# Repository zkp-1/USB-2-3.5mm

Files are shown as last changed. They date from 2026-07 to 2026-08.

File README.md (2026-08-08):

# USB-2-3.5mm
Personal Project to drive analog speakers from USB Type C.
##
I utilized a Cmedia CM108B audio IC and a MAX97720A Amplifier IC. The USB Type C connector is wired with resistors on CC1 and CC2 to allow power draw from the Host. The Cmedia IC then sends an identifier notifying the Host that the device is an audio device, making it load drivers and prepare for audio playthrough. A 90Ω impedance was aimed for in the design, to allow optimal operation on the differential USB data rails. At last, the IC sends the Audio data through its own DACs and internal amplifiers, converting it to analog and being able to be used at the intended 3.5mm output. 

The MAX97220A is set with a gain of 3.52dB and an input impedance of 10k. The output of the MAX IC is wired directly onto the 3.5mm and has an integrated anti-crackle and pop solution inside the IC, which was my main drive to using this IC for amplification.
# PCB 3D KiCAD Renders
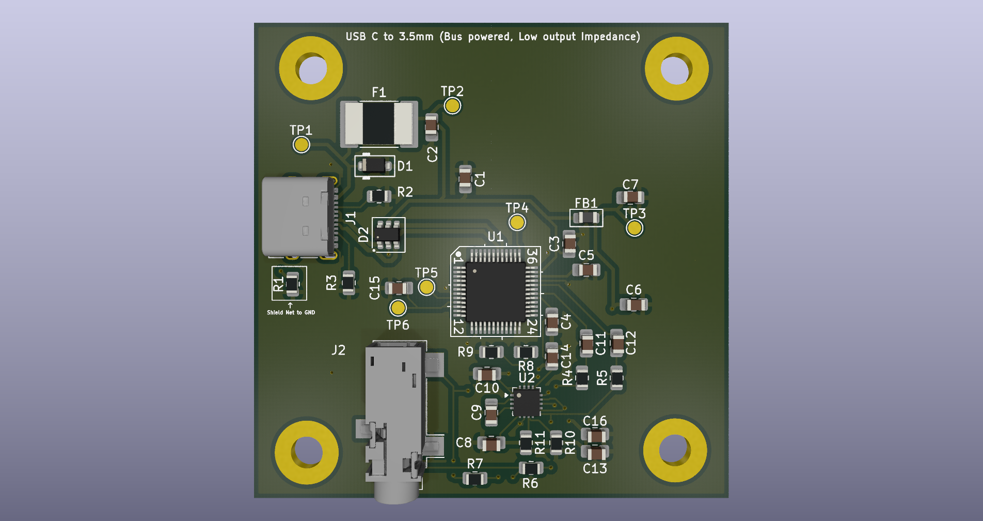
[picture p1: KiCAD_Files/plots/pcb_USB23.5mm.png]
1. 

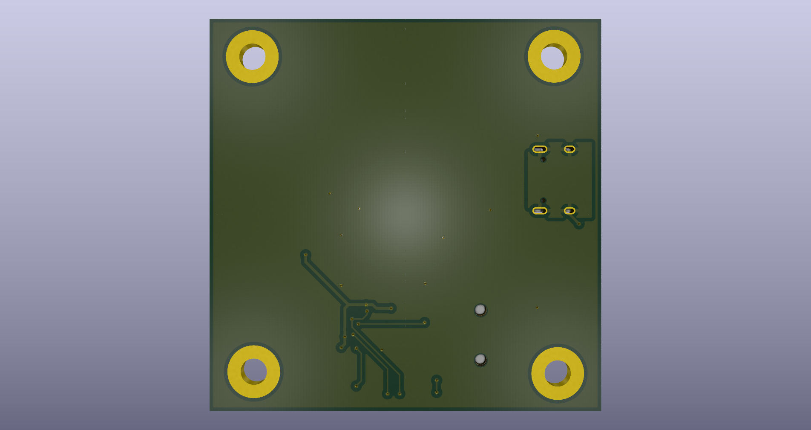
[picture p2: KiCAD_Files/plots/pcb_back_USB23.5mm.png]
2.

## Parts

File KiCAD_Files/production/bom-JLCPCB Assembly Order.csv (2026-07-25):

JLCPCB BOM Tool - BOM Matching
BOM name：bom-JLCPCB Assembly Order.xlsx |  |  | Download Time：2026-07-26 05:52:38 |  |  |  | * Our matching results are updated in real-time, but stock and prices may change. If it's been over 24 hours, please re-match before placing your order.
PCB Assembled Qty：5 |  |  | Est. Total Price：33.1043
Your BOM |  |  |  |  | Matched Parts |  |  |  |  |  |  | Order Information
Top Designator | Bottom Designator | Comment | Footprint | JLCPCB Part # | Matches | Part # | Manufacturer | Footprint | Description | Category | Warning | JLCPCB Part # | Product link | Lib Type | Qty | Source | Total Price ($)
C1,C15,C3,C4,C5,C6 |  | 0.1u | 0805 |  | Unconfirmed | CC0805KRX7R9BB104 | YAGEO | 0805 | 100nF 50V X7R ±10% 0805 Multilayer Ceramic Capacitors MLCC - SMD/SMT ROHS | Multilayer Ceramic Capacitors MLCC - SMD/SMT | 1.The comment (CC0805KRX7R9BB104) of this part does not match the one (0.1u) provided in your BOM. Please confirm; | C49678 | https://jlcpcb.com/partdetail/YAGEO-CC0805KRX7R9BB104/C49678 | Basic | 40 | 40 JLCPCB | 1.284
C10,C13,C14,C16,C8,C9 |  | 1u | 0805 |  | Unconfirmed | CL21B105KBFNNNE | Samsung Electro-Mechanics | 0805 | 1uF 50V X7R ±10% 0805 Multilayer Ceramic Capacitors MLCC - SMD/SMT ROHS | Multilayer Ceramic Capacitors MLCC - SMD/SMT | 1.The comment (CL21B105KBFNNNE) of this part does not match the one (1u) provided in your BOM. Please confirm; | C28323 | https://jlcpcb.com/partdetail/29074-CL21B105KBFNNNE/C28323 | Basic | 40 | 40 JLCPCB | 3.46
C11,C12,C2,C7 |  | 4.7u | 0805 |  | Unconfirmed | CL21A475KAQNNNE | Samsung Electro-Mechanics | 0805 | 25V 4.7uF X5R ±10% 0805 Multilayer Ceramic Capacitors MLCC - SMD/SMT ROHS | Multilayer Ceramic Capacitors MLCC - SMD/SMT | 1.The comment (CL21A475KAQNNNE) of this part does not match the one (4.7u) provided in your BOM. Please confirm; | C1779 | https://jlcpcb.com/partdetail/2131-CL21A475KAQNNNE/C1779 | Basic | 30 | 30 JLCPCB | 1.506
D1 |  | TVS_Uni | D_SOD-123F |  | Select by Customer | M4SMF15CA | Slkor(SLKORMICRO Elec.) | SOD-123FL | 15V 18.5V 180A@8/20us 1uA 26V 500pF Bidirectional TVS SOD-123FL ESD and Surge Protection (TVS/ESD) ROHS |  |  | C46061815 | https://jlcpcb.com/partdetail/Slkor_SLKORMICRO_Elec-M4SMF15CA/C46061815 | Extended | 15 | 15 JLCPCB | 0.624
D2 |  | USBLC6-2SC6 | SOT-23-6 |  | Select by System | USBLC6-2SC6 | TECH PUBLIC | SOT-23-6 | -55℃~+125℃ 0.35pF 12V 150W 2 5V 6A 6V 80nA ESD IEC 61000-4-2、IEC 61000-4-5、IEC 61000-4-4 Unidirectional SOT-23-6 ESD and Surge Protection (TVS/ESD) ROHS | ESD And Surge Protection (TVS/ESD) |  | C2827654 | https://jlcpcb.com/partdetail/TECHPUBLIC-USBLC62SC6/C2827654 | Extended | 9 | 9 JLCPCB | 0.3978
F1 |  | Polyfuse_S | 2920 |  | Select by Customer | 2920L500/6GR | LUTE | 2920 | -40℃~+85℃ 1.6mm 10A 2.5W 31mΩ 40A 5.44mm 5A 5mΩ 5s 6V 7.98mm 2920 Resettable Fuses ROHS | Resettable Fuses |  | C19193059 | https://jlcpcb.com/partdetail/LUTE-2920L5006GR/C19193059 | Extended | 5 | 5 JLCPCB | 0.744
FB1 |  | Ferrite_Bead | Ferrite_0805_2012Metric |  | Select by Customer | ZECB201209A121-4A000 | ZE | 0805 | 1 120Ω@100MHz 4A 50mΩ ±25% 0805 Ferrite Beads ROHS | Inductors (SMD) |  | C2943443 | https://jlcpcb.com/partdetail/ZE-ZECB201209A1214A000/C2943443 | Extended | 20 | 20 JLCPCB | 0.89
J1 |  | USBCReceptacle | USB_C_Receptacle_XKB_U262-16XN-4BVC11 |  | Select by Customer | HX TYPE-C 16PIN | hanxia | SMD | -30℃~+80℃ 1 1.68mm 16P 20V 3A 5,000 times 7.35mm Black Female Surface Mount, Right Angle Type-C USB 3.1 SMD USB Connectors ROHS | USB Connectors |  | C5178539 | https://jlcpcb.com/partdetail/hanxia-HX_TYPE_C16PIN/C5178539 | Extended | 5 | 5 JLCPCB | 0.375
J2 |  | 3.5mmJack | Jack_3.5mm_CUI_SJ-3523-SMT_Horizontal |  | Select by Customer | PJ-320B | SOFNG | SMD | -25℃~+75℃ 24V 25mA 3.5mm Headphone Jack Phosphor Bronze SMD Audio Connectors ROHS | Audio Connectors (Headphones) |  | C22355831 | https://jlcpcb.com/partdetail/SOFNG-PJ320B/C22355831 | Extended | 5 | 5 JLCPCB | 0.2455
R1 |  | 0 | 0805 |  | Unconfirmed | 0805W8F0000T5E | UNI-ROYAL(Uniroyal Elec) | 0805 | -55℃~+155℃ 0Ω 125mW 150V Thick Film Resistor ±1% ±800ppm/℃ 0805 Chip Resistor - Surface Mount ROHS | Chip Resistor - Surface Mount | 1.The comment (0805W8F0000T5E) of this part does not match the one (0) provided in your BOM. Please confirm; | C17477 | https://jlcpcb.com/partdetail/18165-0805W8F0000T5E/C17477 | Basic | 20 | 20 JLCPCB | 0.2
R2,R3 |  | 5.1k | 0805 |  | Unconfirmed | 0805W8F5101T5E | UNI-ROYAL(Uniroyal Elec) | 0805 | -55℃~+155℃ 125mW 150V 5.1kΩ Thick Film Resistor ±1% ±100ppm/℃ 0805 Chip Resistor - Surface Mount ROHS | Chip Resistor - Surface Mount | 1.The comment (0805W8F5101T5E) of this part does not match the one (5.1k) provided in your BOM. Please confirm; | C27834 | https://jlcpcb.com/partdetail/28584-0805W8F5101T5E/C27834 | Basic | 20 | 20 JLCPCB | 0.27
R10,R4,R5,R8 |  | 10k,1% | 0805 |  | Unconfirmed | FRC0805F1002TS | FOJAN | 0805 | -55℃~+155℃ 10kΩ 125mW 150V Thick Film Resistor ±1% ±100ppm/℃ 0805 Chip Resistor - Surface Mount ROHS | Chip Resistor - Surface Mount | 1.The comment (FRC0805F1002TS) of this part does not match the one (10k,1%) provided in your BOM. Please confirm; | C2907219 | https://jlcpcb.com/partdetail/FOJAN-FRC0805F1002TS/C2907219 | Extended | 30 | 30 JLCPCB | 0.12
R11,R6,R7,R9 |  | 15k,1% | 0805 |  | Unconfirmed | FRC0805F1502TS | FOJAN | 0805 | -55℃~+155℃ 125mW 150V 15kΩ Thick Film Resistor ±1% ±100ppm/℃ 0805 Chip Resistor - Surface Mount ROHS | Chip Resistor - Surface Mount | 1.The comment (FRC0805F1502TS) of this part does not match the one (15k,1%) provided in your BOM. Please confirm; | C2930170 | https://jlcpcb.com/partdetail/FOJAN-FRC0805F1502TS/C2930170 | Extended | 30 | 30 JLCPCB | 0.129
U1 |  | CM108B | LQFP-48_7x7mm_P0.5mm |  | Select by System | CM108B | Cmedia | LQFP-48(7x7) | -20℃~+70℃ 4.5V~5.5V 44.1kHz~48kHz Encoder/decoder I2S、USB LQFP-48(7x7) Audio Interface ICs ROHS | Audio Interface ICs |  | C371347 | https://jlcpcb.com/partdetail/Cmedia-CM108B/C371347 | Extended | 5 | 5 JLCPCB | 16.2815
U2 |  | MAXIMMAX97220AETE+T | QFN-16-1EP_3x3mm_P0.5mm_EP1.45x1.45mm |  | Select by Customer | MAX97220AETE+T | Analog Devices Inc./Maxim Integrated | QFN-16-EP(3x3) | -40℃~+85℃ 0.0035% 112.5dB 125mWx2@32Ω 2-Channel 2.5V~5.5V 7mA 90dB Automatic mute/no-noise switch、Enable/disable function QFN-16-EP(3x3) Audio Amplifiers ROHS | Audio Amplifiers |  | C2682711 | https://jlcpcb.com/partdetail/2777742-MAX97220AETET/C2682711 | Extended | 5 | 5 JLCPCB | 6.5775
TP1 |  | VBUS | TestPoint_Pad_D1.5mm |  | No matches | No Part Selected
TP2 |  | +5V | TestPoint_Pad_D1.5mm |  | No matches | No Part Selected
TP3 |  | +5V_Analog | TestPoint_Pad_D1.5mm |  | No matches | No Part Selected
TP4 |  | 3.6V | TestPoint_Pad_D1.5mm |  | No matches | No Part Selected
TP5 |  | 1.8V | TestPoint_Pad_D1.5mm |  | No matches | No Part Selected
TP6 |  | 3.3V | TestPoint_Pad_D1.5mm |  | No matches | No Part Selected
_3,_2 |  |  |  |  | No matches | No Part Selected

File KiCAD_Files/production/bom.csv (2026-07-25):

Designator | Footprint | Quantity | Value | LCSC Part #
_3, _2, |  | 3
C1, C15, C3, C4, C5, C6 | 0805 | 6 | 0.1u
C10, C13, C14, C16, C8, C9 | 0805 | 6 | 1u
C11, C12, C2, C7 | 0805 | 4 | 4.7u
D1 | D_SOD-123F | 1 | TVS_Uni
D2 | SOT-23-6 | 1 | USBLC6-2SC6
F1 | 2920 | 1 | Polyfuse_S
FB1 | Ferrite_0805_2012Metric | 1 | Ferrite_Bead
J1 | USB_C_Receptacle_XKB_U262-16XN-4BVC11 | 1 | USB C Receptacle
J2 | Jack_3.5mm_CUI_SJ-3523-SMT_Horizontal | 1 | 3.5mm Jack
R1 | 0805 | 1 | 0
R10, R4, R5, R8 | 0805 | 4 | 10k, 1%
R11, R6, R7, R9 | 0805 | 4 | 15k, 1%
R2, R3 | 0805 | 2 | 5.1k
TP1 | TestPoint_Pad_D1.5mm | 1 | VBUS
TP2 | TestPoint_Pad_D1.5mm | 1 | +5V
TP3 | TestPoint_Pad_D1.5mm | 1 | +5V_Analog
TP4 | TestPoint_Pad_D1.5mm | 1 | 3.6V
TP5 | TestPoint_Pad_D1.5mm | 1 | 1.8V
TP6 | TestPoint_Pad_D1.5mm | 1 | 3.3V
U1 | LQFP-48_7x7mm_P0.5mm | 1 | CM108B
U2 | QFN-16-1EP_3x3mm_P0.5mm_EP1.45x1.45mm | 1 | MAXIM MAX97220AETE+T

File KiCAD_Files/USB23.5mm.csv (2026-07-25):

Reference | Qty | Value | DNP | Exclude from BOM | Exclude from Board | Footprint | Datasheet
C1,C3,C4,C5,C6,C15 | 6 | 0.1u |  |  |  | Capacitor_SMD:C_0805_2012Metric_Pad1.18x1.45mm_HandSolder
C2,C7,C11,C12 | 4 | 4.7u |  |  |  | Capacitor_SMD:C_0805_2012Metric_Pad1.18x1.45mm_HandSolder
C8,C9,C10,C13,C14,C16 | 6 | 1u |  |  |  | Capacitor_SMD:C_0805_2012Metric_Pad1.18x1.45mm_HandSolder
D1 | 1 | TVS_Uni |  |  |  | PCM_Diode_SMD_Handsoldering_AKL:D_SOD-123F
D2 | 1 | USBLC6-2SC6 |  |  |  | PCM_Package_TO_SOT_SMD_AKL:SOT-23-6 | https://www.tme.eu/Document/db59d28d28a96c34f26d05f234ff409c/USBLC6-2.pdf
F1 | 1 | Polyfuse_S |  |  |  | Fuse:Fuse_2920_7451Metric_Pad2.10x5.45mm_HandSolder
FB1 | 1 | Ferrite_Bead |  |  |  | PCM_Ferrite_SMD_Handsoldering_AKL:Ferrite_0805_2012Metric
J1 | 1 | USB C Receptacle |  |  |  | Connector_USB:USB_C_Receptacle_XKB_U262-16XN-4BVC11 | https://www.usb.org/sites/default/files/documents/usb_type-c.zip
J2 | 1 | 3.5mm Jack |  |  |  | Connector_Audio:Jack_3.5mm_CUI_SJ-3523-SMT_Horizontal | https://www.lcsc.com/datasheet/C521460.pdf
R1 | 1 | 0 |  |  |  | Resistor_SMD:R_0805_2012Metric
R2,R3 | 2 | 5.1k |  |  |  | Resistor_SMD:R_0805_2012Metric
R4,R5,R8,R10 | 4 | 10k, 1% |  |  |  | Resistor_SMD:R_0805_2012Metric
R6,R7,R9,R11 | 4 | 15k, 1% |  |  |  | Resistor_SMD:R_0805_2012Metric
TP1 | 1 | VBUS |  |  |  | TestPoint:TestPoint_Pad_D1.5mm
TP2 | 1 | +5V |  |  |  | TestPoint:TestPoint_Pad_D1.5mm
TP3 | 1 | +5V_Analog |  |  |  | TestPoint:TestPoint_Pad_D1.5mm
TP4 | 1 | 3.6V |  |  |  | TestPoint:TestPoint_Pad_D1.5mm
TP5 | 1 | 1.8V |  |  |  | TestPoint:TestPoint_Pad_D1.5mm
TP6 | 1 | 3.3V |  |  |  | TestPoint:TestPoint_Pad_D1.5mm
U1 | 1 | CM108B |  |  |  | PCM_Package_QFP_AKL:LQFP-48_7x7mm_P0.5mm | https://www.micros.com.pl/mediaserver/info-uicm108b.pdf
U2 | 1 | MAXIM MAX97220AETE+T |  |  |  | Package_DFN_QFN:QFN-16-1EP_3x3mm_P0.5mm_EP1.45x1.45mm | https://www.analog.com/media/en/technical-documentation/data-sheets/max97220a-max97220e.pdf

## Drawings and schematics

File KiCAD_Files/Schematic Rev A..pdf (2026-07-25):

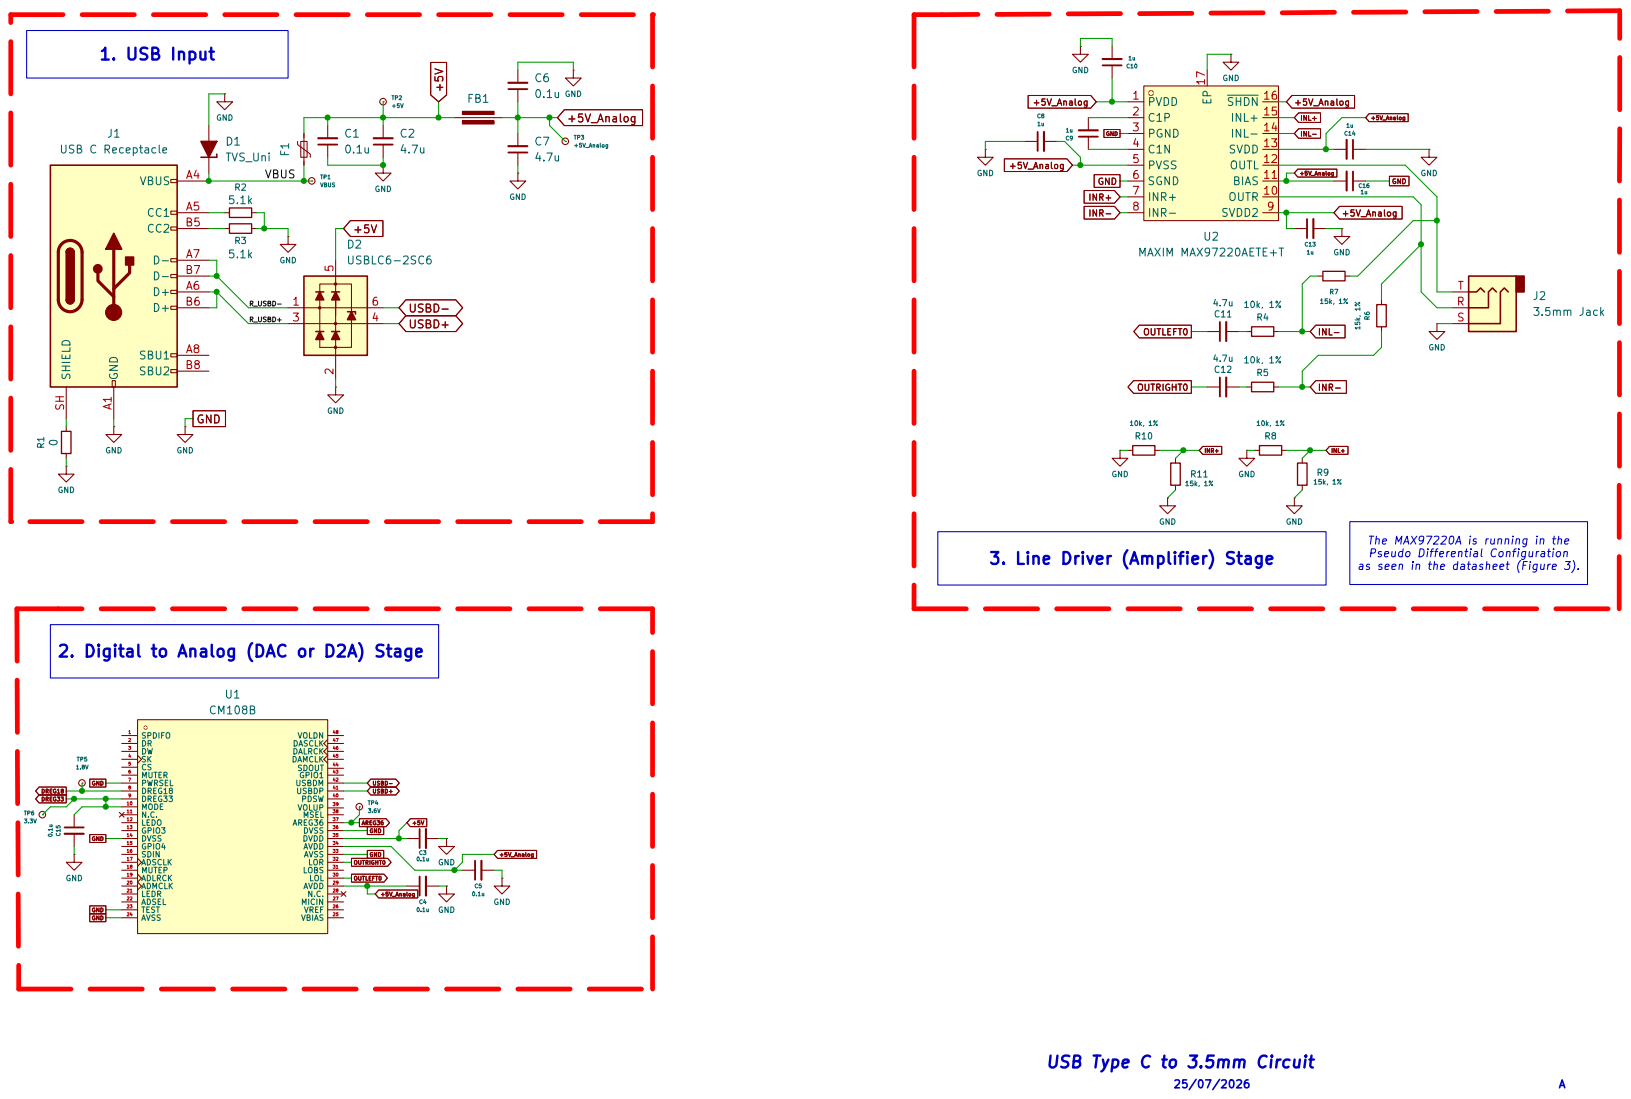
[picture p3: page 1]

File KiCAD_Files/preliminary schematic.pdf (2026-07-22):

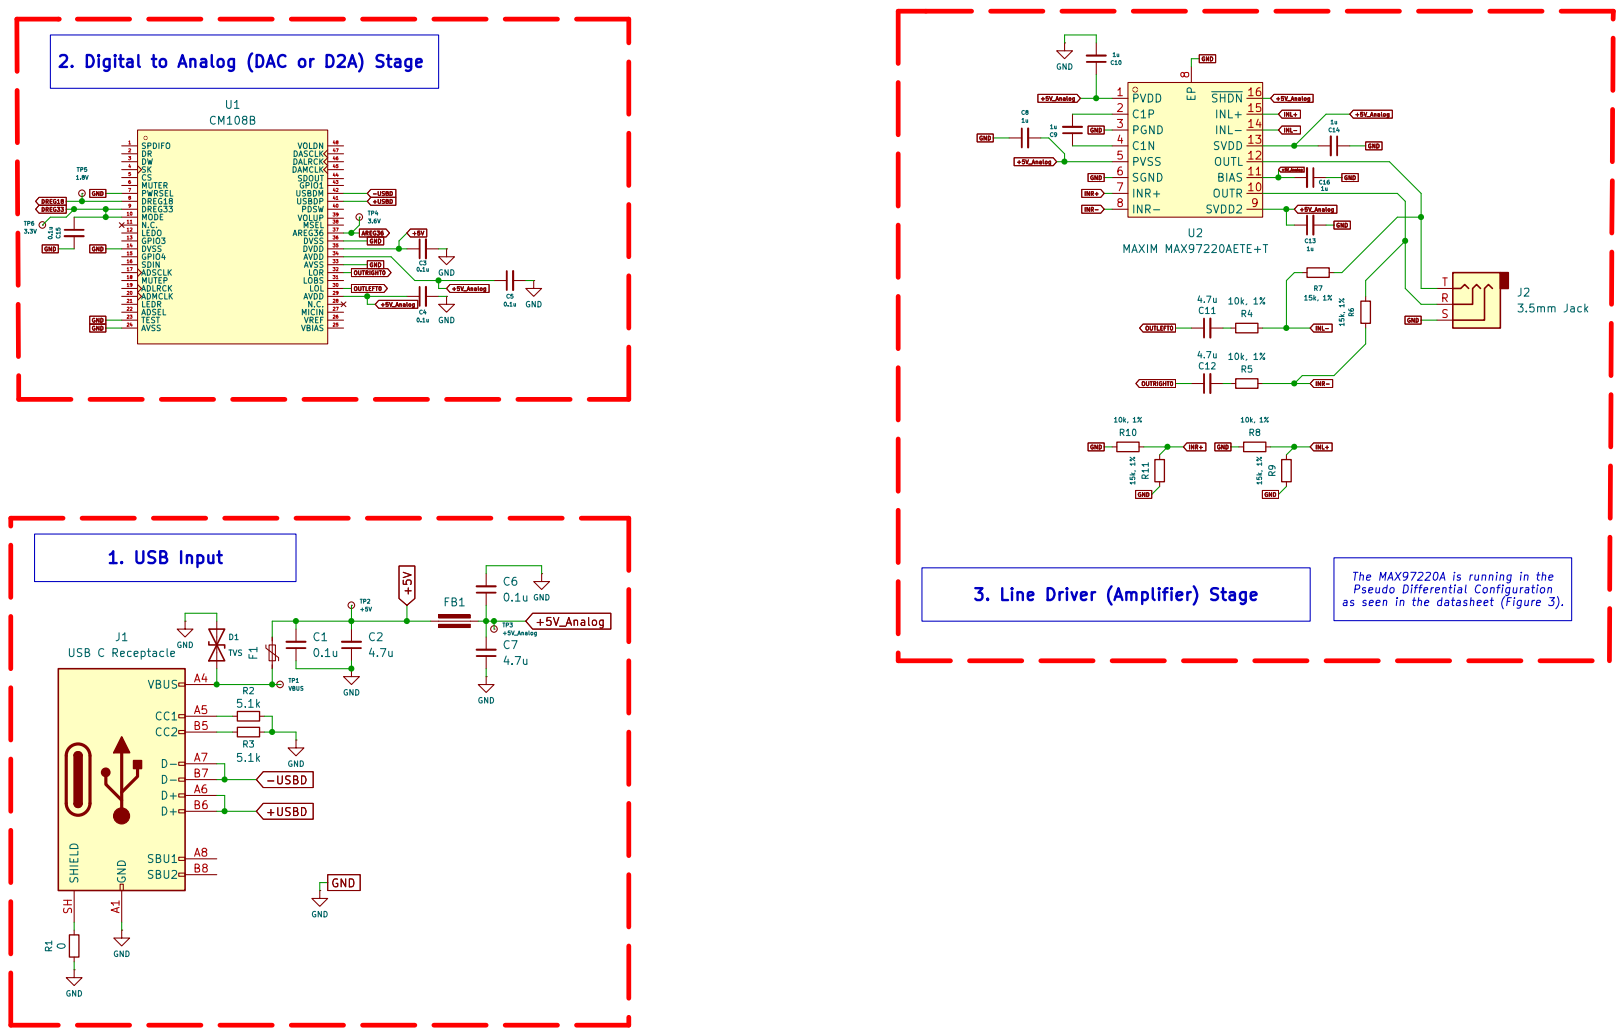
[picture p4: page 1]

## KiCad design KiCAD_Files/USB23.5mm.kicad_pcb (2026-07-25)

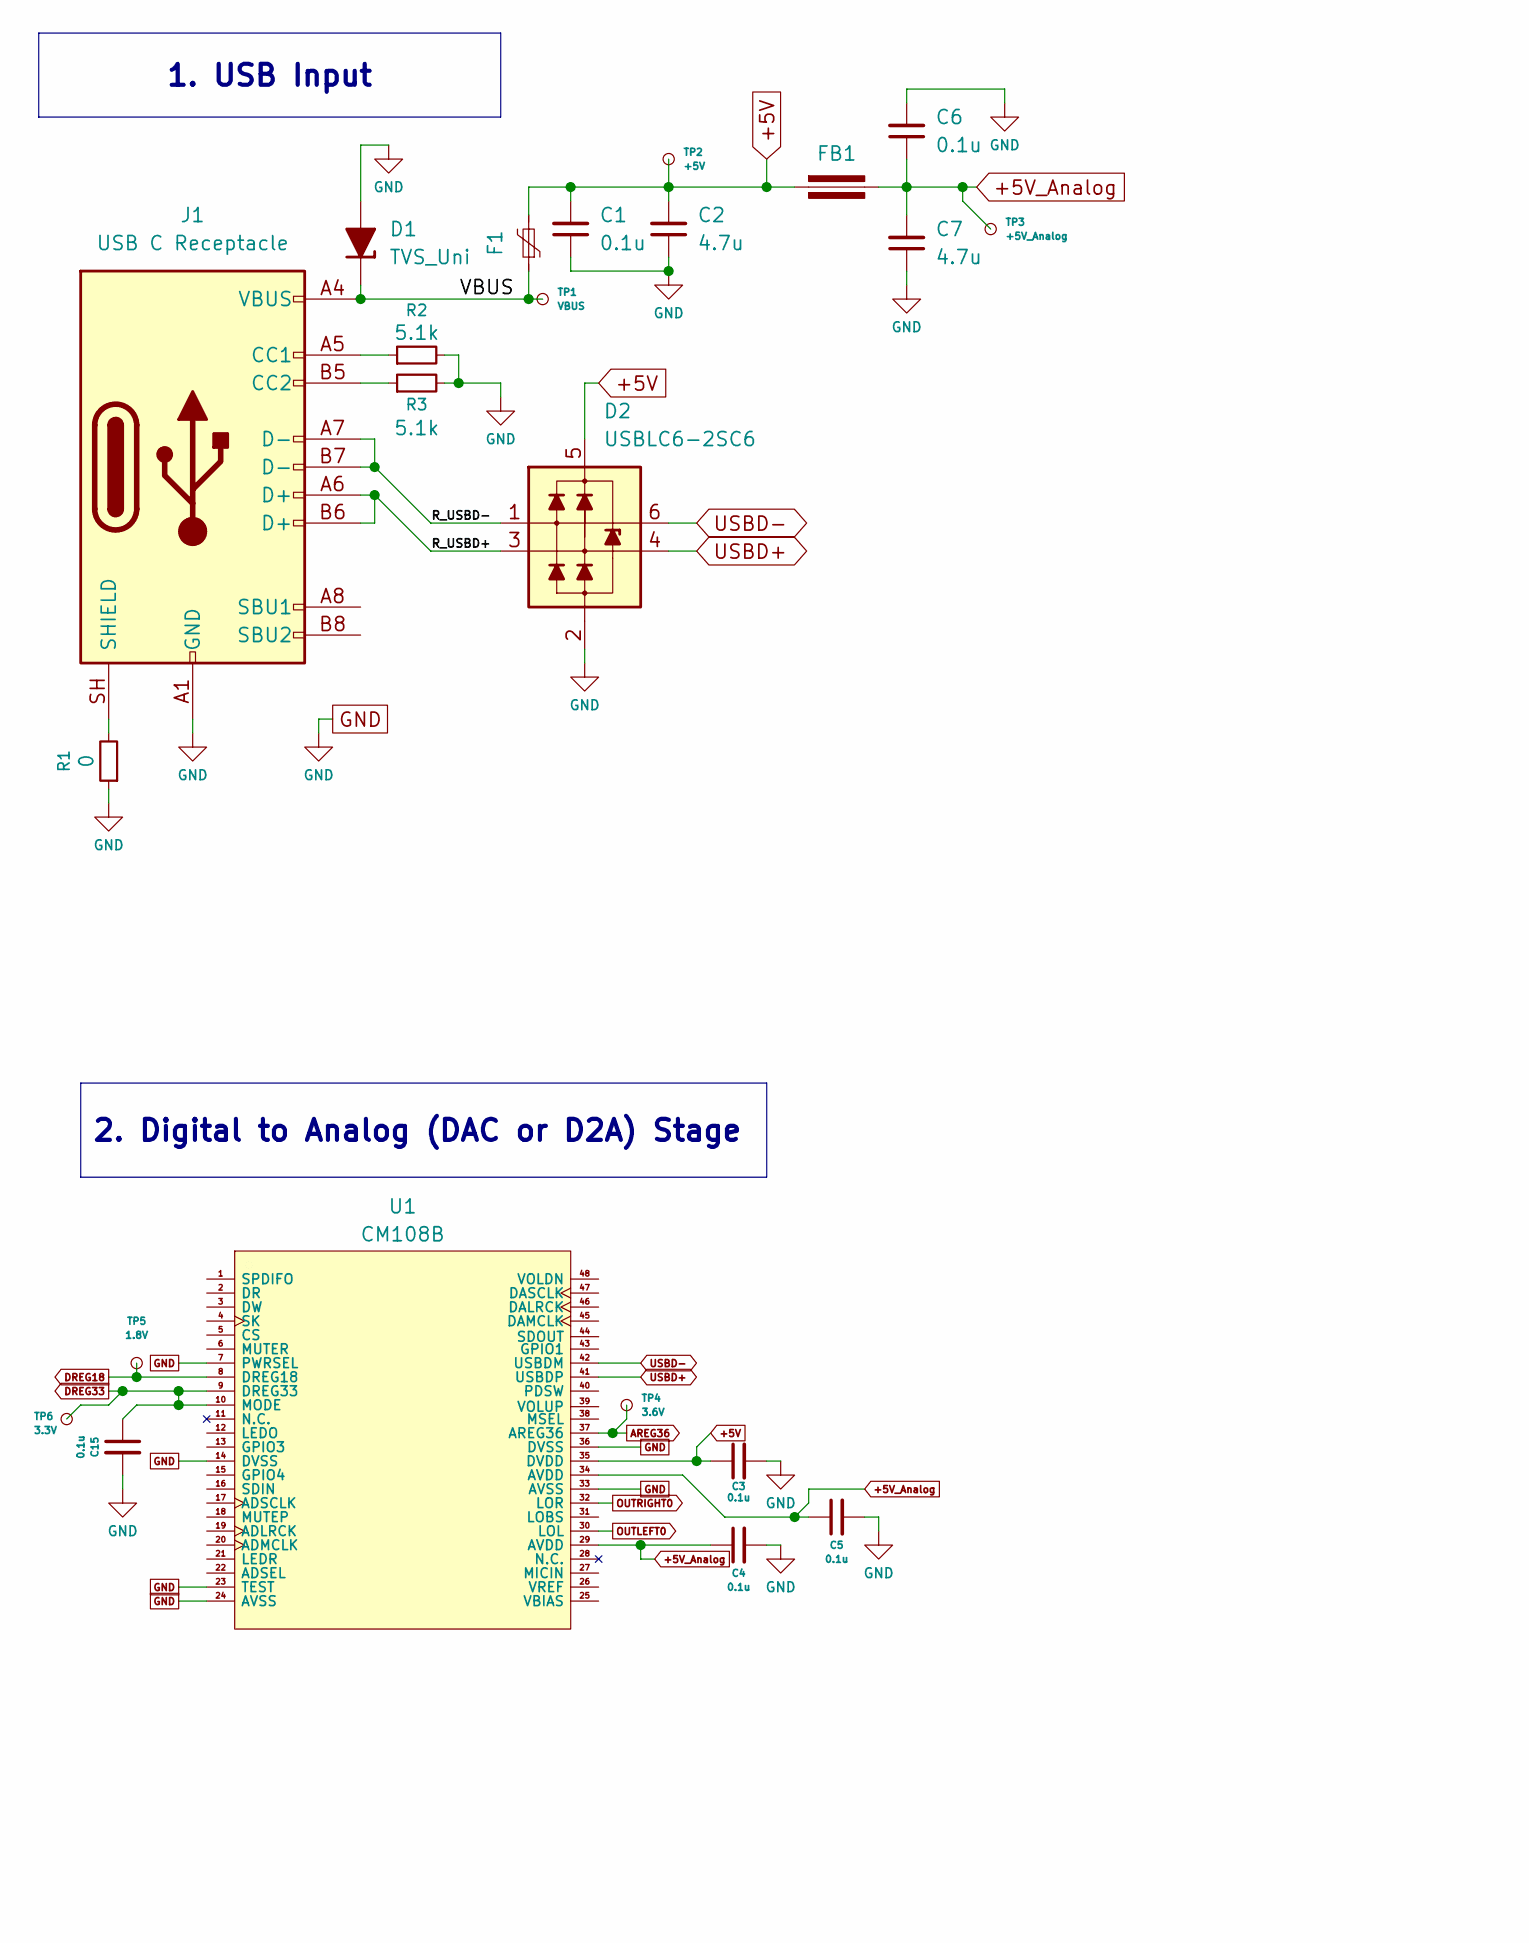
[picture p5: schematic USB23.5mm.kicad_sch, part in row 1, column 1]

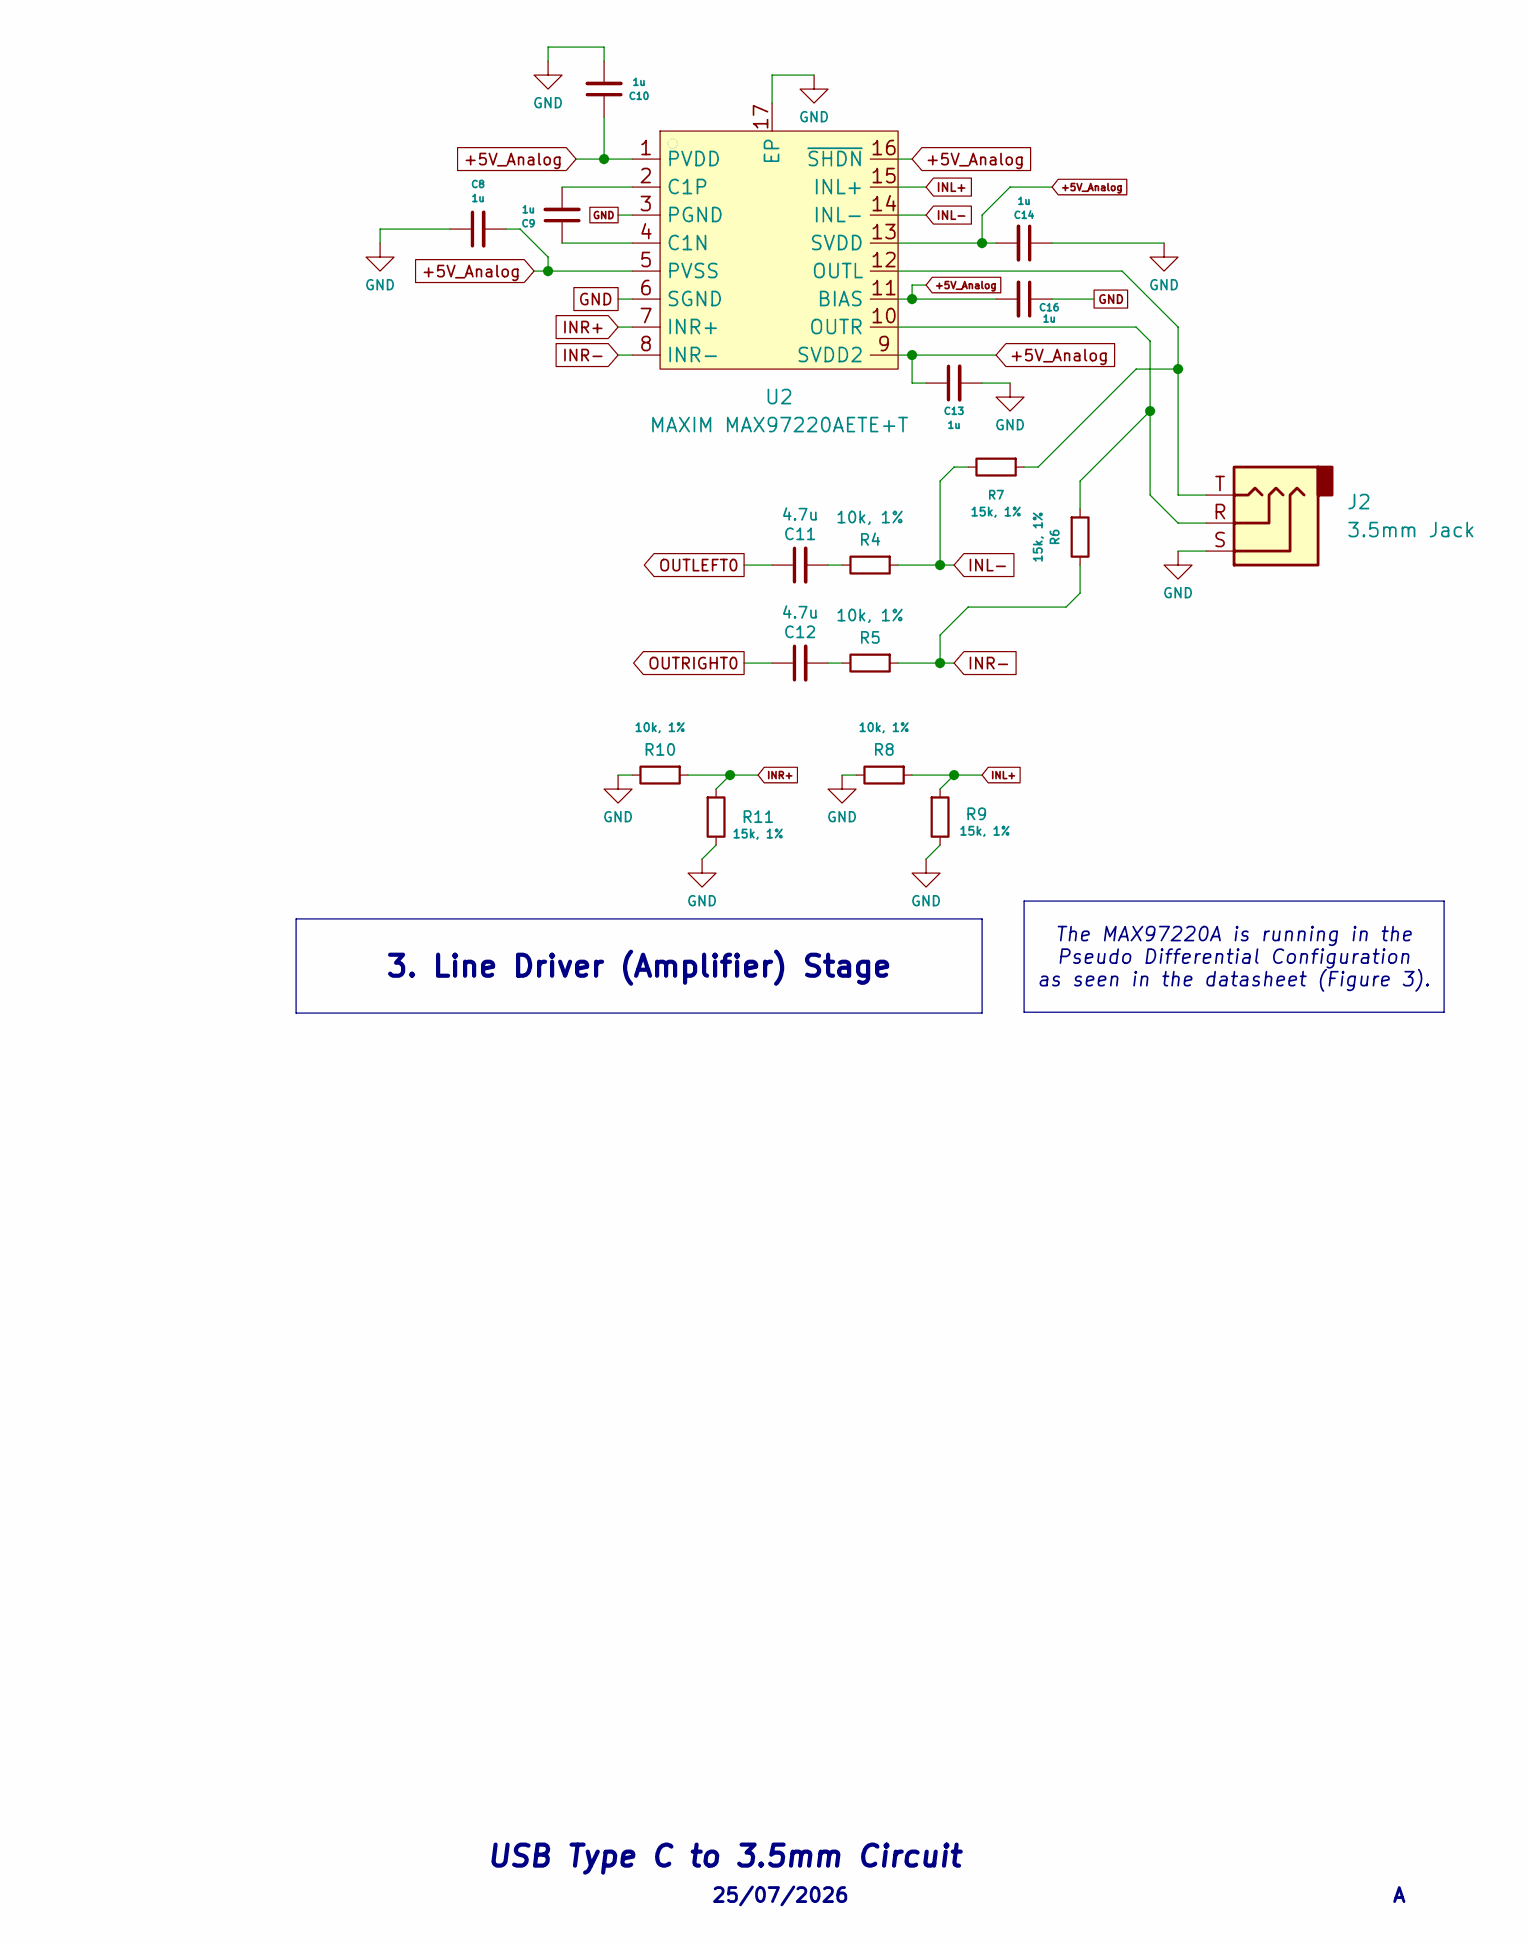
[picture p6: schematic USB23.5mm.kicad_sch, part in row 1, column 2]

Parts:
C1, C3, C4, C5, C6, C15: 0.1u; C_0805_2012Metric_Pad1.18x1.45mm_HandSolder
C2, C7, C11, C12: 4.7u; C_0805_2012Metric_Pad1.18x1.45mm_HandSolder
C8, C9, C10, C13, C14, C16: 1u; C_0805_2012Metric_Pad1.18x1.45mm_HandSolder
D1: TVS_Uni; D_SOD-123F
D2: USBLC6-2SC6; SOT-23-6
F1: Polyfuse_S; Fuse_2920_7451Metric_Pad2.10x5.45mm_HandSolder
FB1: Ferrite_Bead; Ferrite_0805_2012Metric
J1: USB C Receptacle; USB_C_Receptacle_XKB_U262-16XN-4BVC11
J2: 3.5mm Jack; Jack_3.5mm_CUI_SJ-3523-SMT_Horizontal
R1: 0; R_0805_2012Metric
R2, R3: 5.1k; R_0805_2012Metric
R4, R5, R8, R10: 10k, 1%; R_0805_2012Metric
R6, R7, R9, R11: 15k, 1%; R_0805_2012Metric
TP1: VBUS; TestPoint_Pad_D1.5mm
TP2: +5V; TestPoint_Pad_D1.5mm
TP3: +5V_Analog; TestPoint_Pad_D1.5mm
TP4: 3.6V; TestPoint_Pad_D1.5mm
TP5: 1.8V; TestPoint_Pad_D1.5mm
TP6: 3.3V; TestPoint_Pad_D1.5mm
U1: CM108B; LQFP-48_7x7mm_P0.5mm
U2: MAXIM MAX97220AETE+T; QFN-16-1EP_3x3mm_P0.5mm_EP1.45x1.45mm

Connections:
+5V: C1.2, C2.2, C3.1, D2.5 (VP), F1.2, FB1.1, TP2.1 (1_1), U1.35 (DVDD)
+5V_Analog: C4.1, C5.1, C6.1, C7.2, C8.2, C10.1, C13.1, C14.2, C16.2, FB1.2, TP3.1 (1_1), U1.29 (AVDD), U1.34 (AVDD), U2.1 (PVDD), U2.5 (PVSS), U2.9 (SVDD2), U2.11 (BIAS), U2.13 (SVDD), U2.16 (~SHDN)
/R_USBD+: D2.3 (L2), J1.A6 (D+), J1.B6 (D+)
/R_USBD-: D2.1 (L1), J1.A7 (D-), J1.B7 (D-)
/VBUS: D1.1 (K), F1.1, J1.A4 (VBUS), J1.A9 (VBUS), J1.B4 (VBUS), J1.B9 (VBUS), TP1.1 (1_1)
AREG36: TP4.1 (1_1), U1.37 (AREG36)
DREG18: TP5.1 (1_1), U1.8 (DREG18)
DREG33: C15.1, TP6.1 (1_1), U1.9 (DREG33), U1.10 (MODE)
GND: C1.1, C2.1, C3.2, C4.2, C5.2, C6.2, C7.1, C8.1, C10.2, C13.2, C14.1, C15.2, C16.1, D1.2 (A), D2.2 (VN), J1.A1 (GND), J1.A12 (GND), J1.B1 (GND), J1.B12 (GND), J2.S, R1.1, R2.2, R3.2, R8.2, R9.2, R10.2, R11.2, U1.7 (PWRSEL), U1.14 (DVSS), U1.23 (TEST), U1.24 (AVSS), U1.33 (AVSS), U1.36 (DVSS), U2.3 (PGND), U2.6 (SGND), U2.17 (EP)
INL+: R8.1, R9.1, U2.15 (INL+)
INL-: R4.1, R7.2, U2.14 (INL-)
INR+: R10.1, R11.1, U2.7 (INR+)
INR-: R5.1, R6.2, U2.8 (INR-)
unnamed: C11.2, R4.2
unnamed: C12.2, R5.2
unnamed: J1.A5 (CC1), R2.1
unnamed: J1.B5 (CC2), R3.1
unnamed: J1.SH (SHIELD), R1.2
unnamed: C9.1, U2.4 (C1N)
unnamed: C9.2, U2.2 (C1P)
unnamed: J2.T, R7.1, U2.12 (OUTL)
unnamed: J2.R, R6.1, U2.10 (OUTR)
OUTLEFT0: C11.1, U1.30 (LOL)
OUTRIGHT0: C12.1, U1.32 (LOR)
USBD+: D2.4 (L2), U1.41 (USBDP)
USBD-: D2.6 (L1), U1.42 (USBDM)

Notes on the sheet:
25/07/2026
USB Type C to 3.5mm Circuit
1. USB Input
2. Digital to Analog (DAC or D2A) Stage
The MAX97220A is running in the Pseudo Differential Configuration as seen in the datasheet (Figure 3).
3. Line Driver (Amplifier) Stage

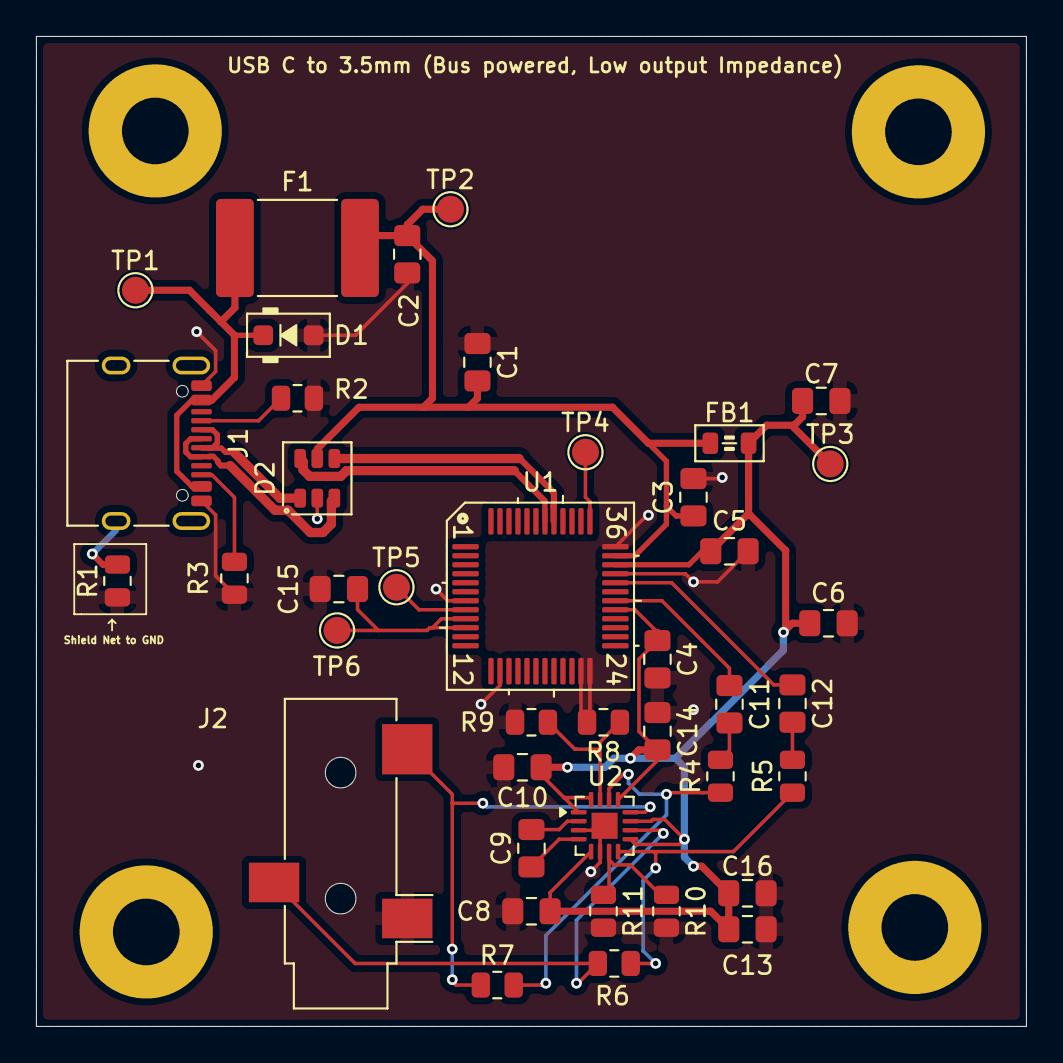
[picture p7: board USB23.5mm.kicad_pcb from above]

Board: 2 copper layers, 55.0 x 55.0 mm, 41 parts (0 on the bottom side), 26 nets.

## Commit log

2026-07-22 Add Project Files
    Preliminary schematic.
    PCB is not created yet.
    [USB23.5mm.kicad_sch]
2026-07-25 Revision A
    Upload of First Revision of the board.
    USB Signal integrity and output was revised.
    PCB was designed, and gerber files have been plotted for production. JLCPCB BOM file is present dated 25/07/2026.
    [USB23.5mm.csv, USB23.5mm.kicad_pcb, USB23.5mm.kicad_sch]
2026-07-25 Prod folder
    [bom-JLCPCB Assembly Order (1).csv, bom-JLCPCB Assembly Order (1).xls, bom-JLCPCB Assembly Order (2).csv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]
2026-07-25 Add USB23.5mm KiCad production files
    [USB23.5mm-B_Cu.gbr, USB23.5mm-B_Mask.gbr, USB23.5mm-B_Paste.gbr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]
